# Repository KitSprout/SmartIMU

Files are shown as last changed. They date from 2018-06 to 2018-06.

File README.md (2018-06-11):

SmartIMU
========





SmartIMU 是一個集成微控制器（STM32F411）、3-Axis 加速度計、3-Axis 陀螺儀、3-Axis 電子羅盤與氣壓計（MPU9250、LPS22HB）以及無線傳輸（NRF52810）於一體的 10DOF 模組，控制器透過 UART 連接無線傳輸芯片，可以將感測器資料無線傳輸至其他裝置觀察。板上除了有 LED、按鍵、電源管理以及 RF 功率放大外，亦拉出至多 25pin 帶 ADC、UART、SPI、I2C 等功能的可用 I/O，1.27mm 間距的擴充腳位上下皆可連接，方便擴充不同應用，像是小型四軸飛行器。

Hardware
========
* 控制器 : [STM32F411CE](http://www.st.com/en/microcontrollers/stm32f411ce.html) 48Pin 100MHz DSP FPU / [nRF52810](https://www.nordicsemi.com/eng/Products/nRF52810) 32Pin 64MHz DSP
* 感測器 : [MPU9250](https://www.invensense.com/products/motion-tracking/9-axis/mpu-9250/) + [LPS22HB](http://www.st.com/content/st_com/en/products/mems-and-sensors/pressure-sensors/lps22hb.html)
* 設計軟體 [Altium Designer 17](http://www.altium.com/altium-designer/overview) ( PcbLib use AD [PcbLib v3.5](https://github.com/KitSprout/AltiumDesigner_PcbLibrary/releases/tag/v3.5) )

View
========

<br />

[more photo ...](https://goo.gl/photos/EfpjMtSc4LyJ7H2Q7)

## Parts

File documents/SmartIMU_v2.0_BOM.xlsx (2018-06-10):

Description | Type | Value | Quantity | Designator | Specification
Resistor | 0402 | 150R | 1 | R10 | -
 | 0402 | 680R | 1 | R7, R9 | -
 | 0402 | 1K | 4 | R1, R11, R12 | -
 | 0402 | 1.5K | 1 | R8 | -
 | 0402 | 10K | 5 | R2, R3, R4, R5, R6 | -
Capacitor | 0402 | 0.8pF | 1 | C26 | -
 | 0402 | 1.2pF | 1 | C27 | -
 | 0402 | 10pF | 4 | C12, C13, C21, C22 | -
 | 0402 | 100pF | 1 | C19 | -
 | 0402 | 220pF | 1 | C25 | -
 | 0402 | 10nF | 1 | C5 | -
 | 0402 | 0.1uF | 14 | C6, C7, C8, C9, C10, C14, C15, C16, C18, C24, C28, C29, C30, C31 | -
 | 0402 | 1uF | 1 | C20 | -
 | 0402 | 2.2uF | 3 | C3, C4, C11 | -
 | 0402 | 4.7uF | 2 | C17, C23 | -
 | 0805 | 4.7uF | 1 | C1 | -
 | 0805 | 22uF | 1 | C2 | -
Inductor | 0402 | 3.9nH | 1 | L4 | -
 | 0402 | 15nH | 1 | L2 | -
 | 0603 | 10uH | 1 | L3
 | 1008 | 4.7uH | 1 | L1 | -
Diode | SOD323 | ZLLS410TA | 1 | D1 | Schottky
LED | 0402 | BLUE | 1 | D4 | -
 | 0603 | WHITE | 1 | D2 | -
 | 1616 | RGB | 1 | D3 | -
IC | SOT23-5 | TPS613222A | 1 | U1 | Boost
 | SOT23-5 | XC6210-33 | 1 | U2 | 3V3
 | QFN48 P0.5 | STM32F411 | 1 | U3 | 100MHz
 | QFN32 P0.5 | nRF52810 | 1 | U4 | 64MHz
 | QFN16 P0.5 | RFX2401C | 1 | U5 | -
 | QFN24 P0.4 | MPU9250 | 1 | U6 | -
 | LGA10 P0.5 | LPS22HB | 1 | U7 | -
Crystal Oscillator | XTAL2016 | 16MHz | 1 | Y1 | -
 | XTAL2016 | 32MHz | 1 | Y2 | -
Connector | Micro USB | B-type | 1 | CON1 | -
 | MX | MX1.25_2P | 1 | CON2 | -
Button | 3.4x3.5 | TACT 4P | 1 | K1 | TACT 4P
Antenna | 3.2x1.6 | -0.5 dBi | 1 | A1 | 2.4GHz 50R

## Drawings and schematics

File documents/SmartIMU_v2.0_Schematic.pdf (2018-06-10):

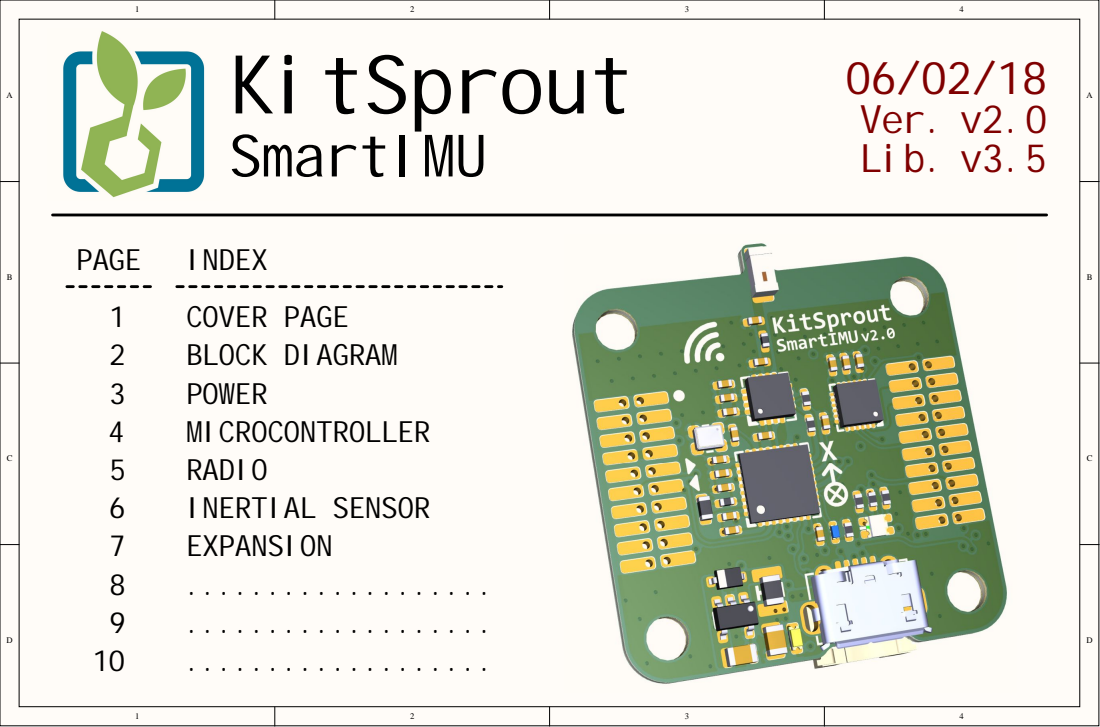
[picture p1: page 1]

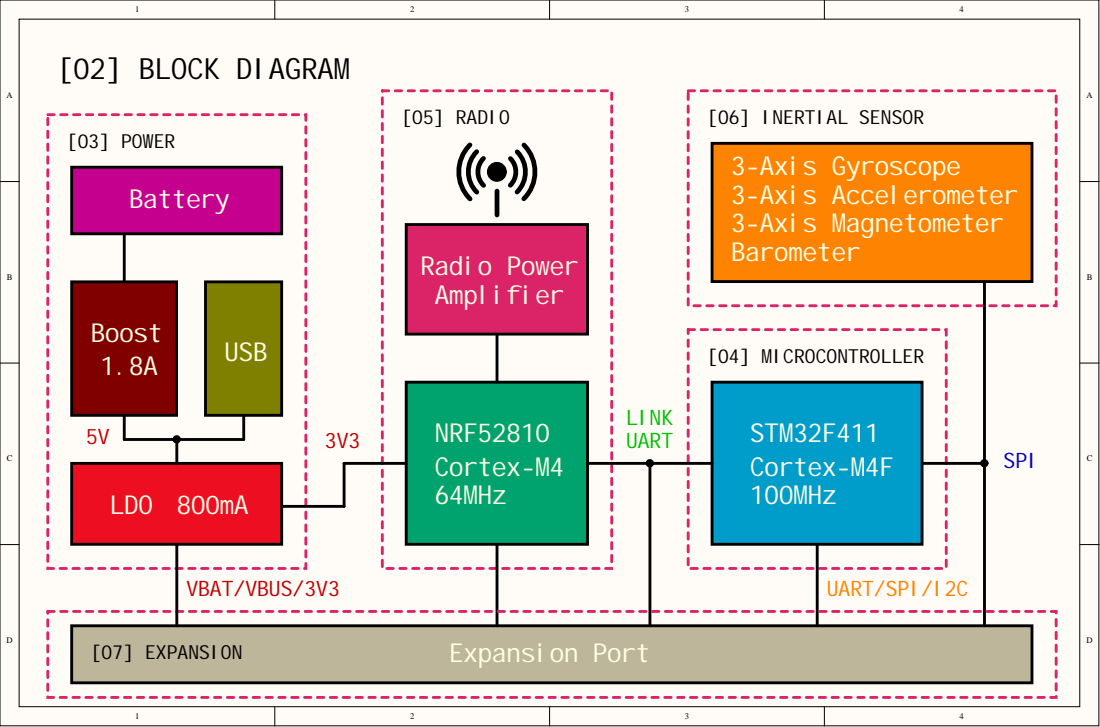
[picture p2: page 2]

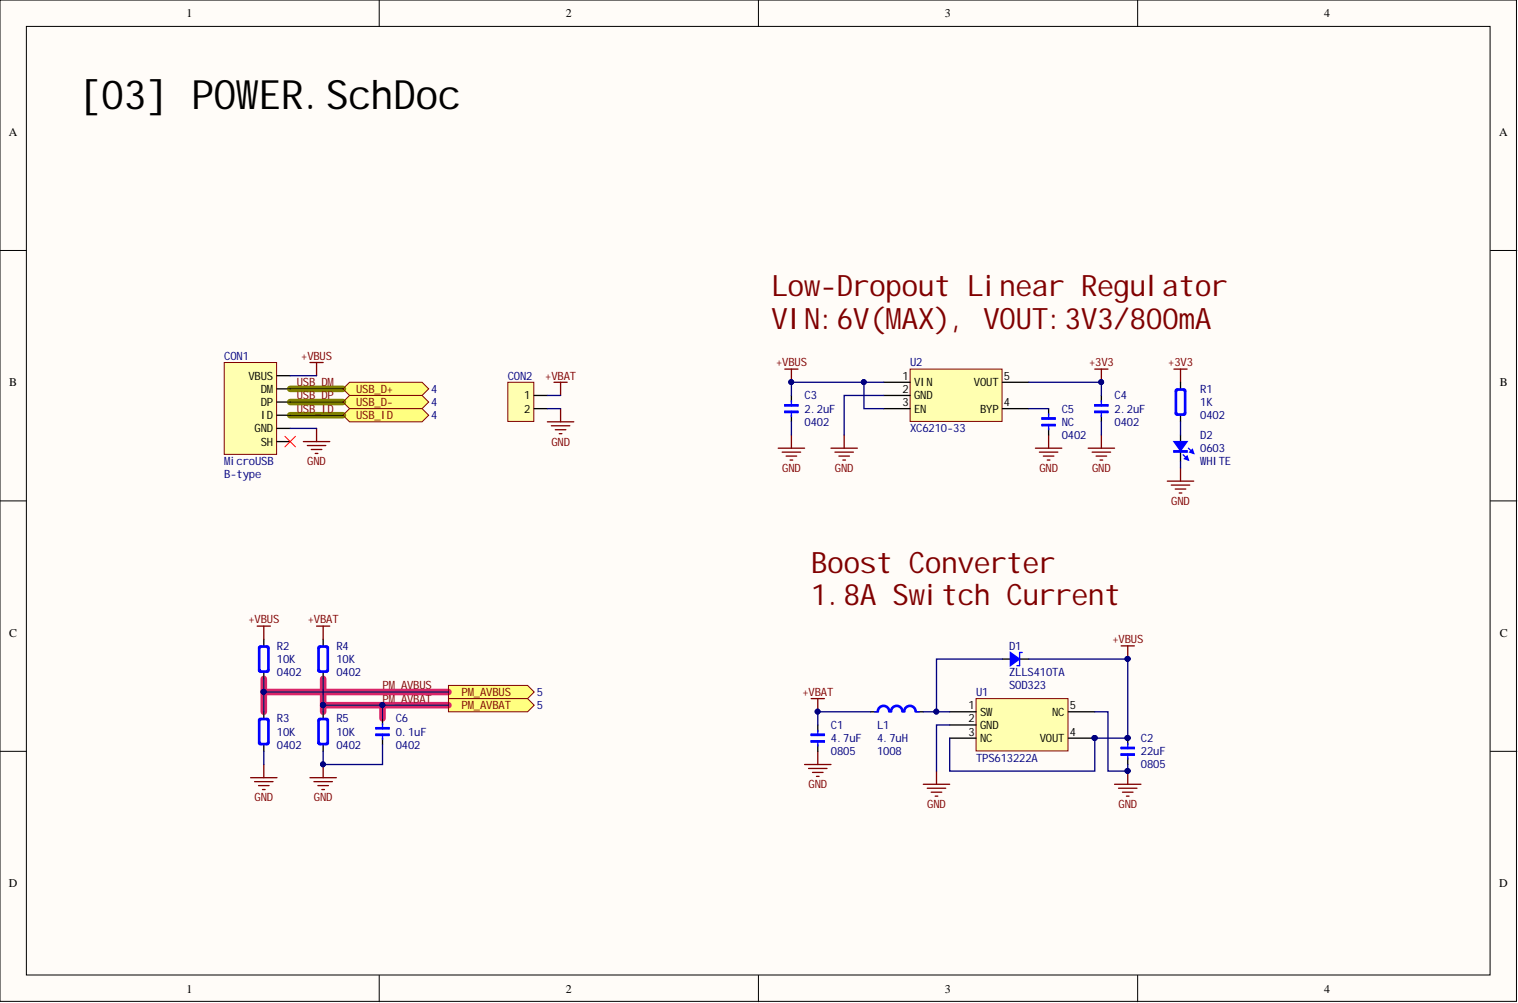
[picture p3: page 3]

Low-Dropout Linear Regulator
VIN:6V(MAX), VOUT:3V3/800mA

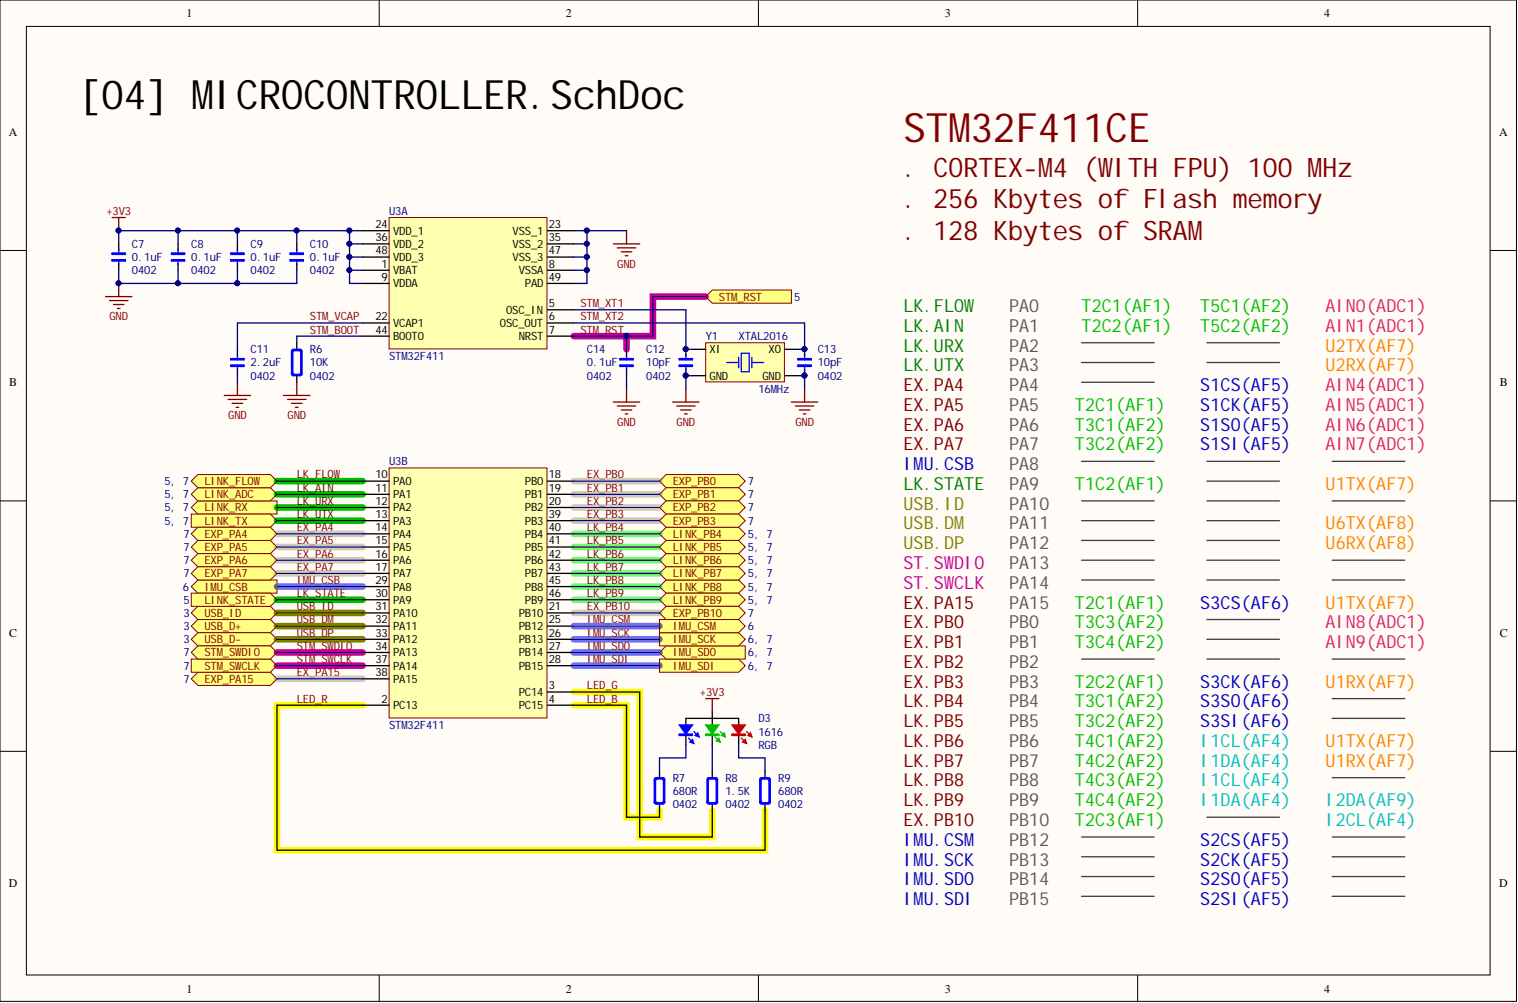
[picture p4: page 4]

STM32F411CE
. CORTEX-M4 (WITH FPU) 100 MHz
. 256 Kbytes of Flash memory
. 128 Kbytes of SRAM

GND | GND

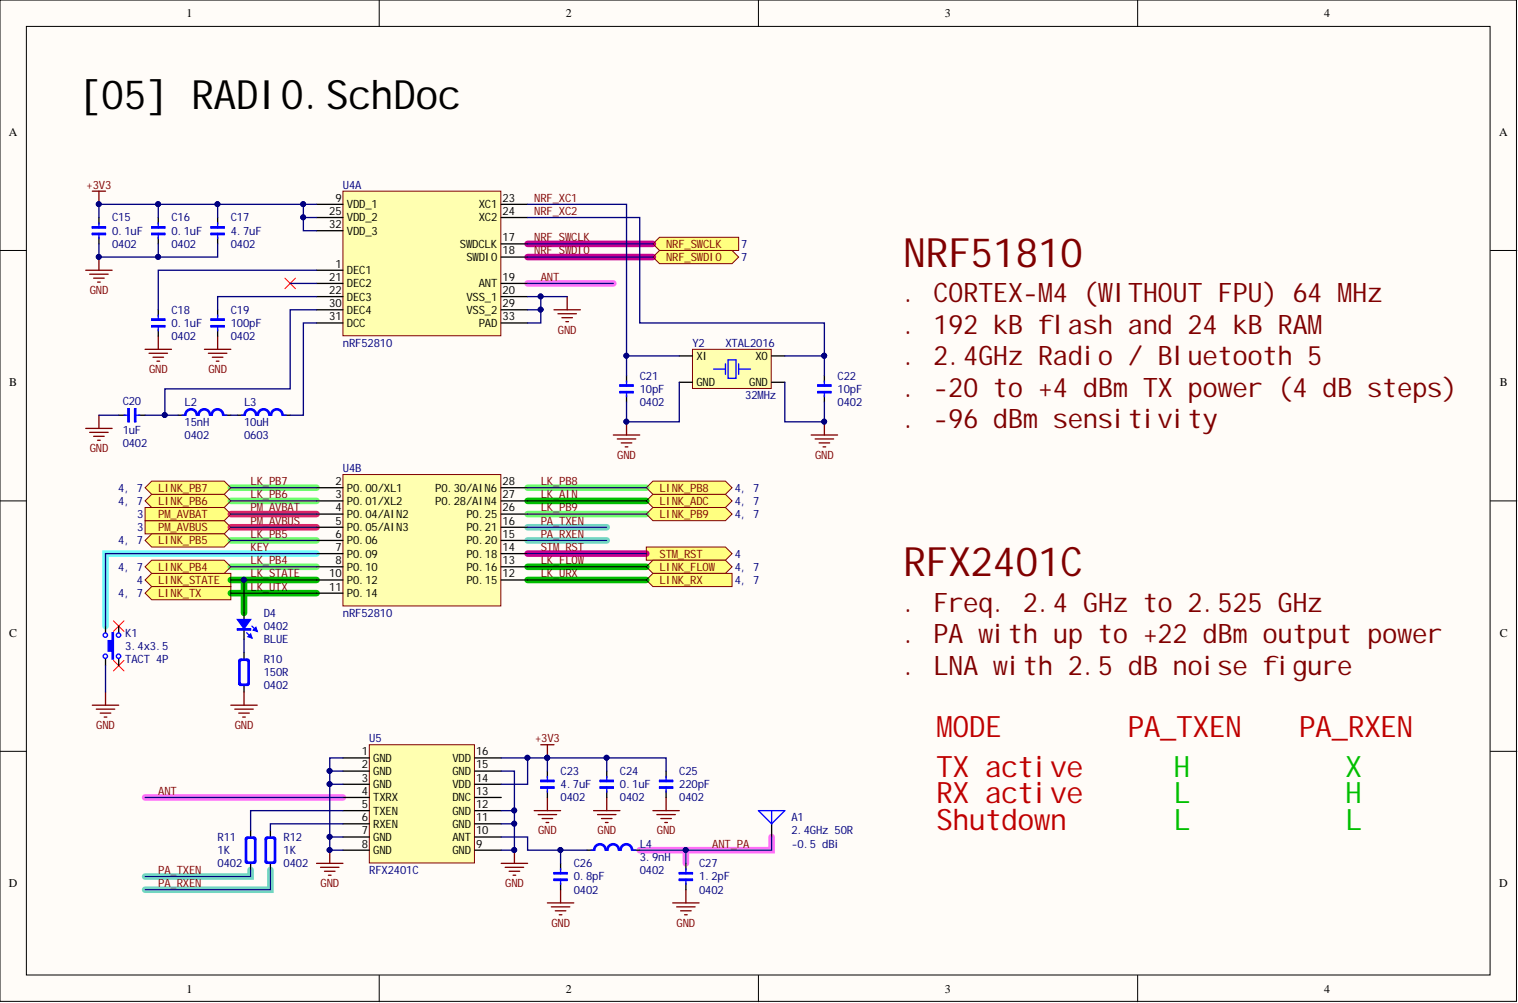
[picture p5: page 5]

NRF51810
. CORTEX-M4 (WITHOUT FPU) 64 MHz
. 192 kB flash and 24 kB RAM
. 2.4GHz Radio / Bluetooth 5
. -20 to +4 dBm TX power (4 dB steps)
. -96 dBm sensitivity

GND | GND

RFX2401C
. Freq. 2.4 GHz to 2.525 GHz
. PA with up to +22 dBm output power
. LNA with 2.5 dB noise figure

GND 2

TXRX 4
TXEN 5
RXEN 6
GND 7

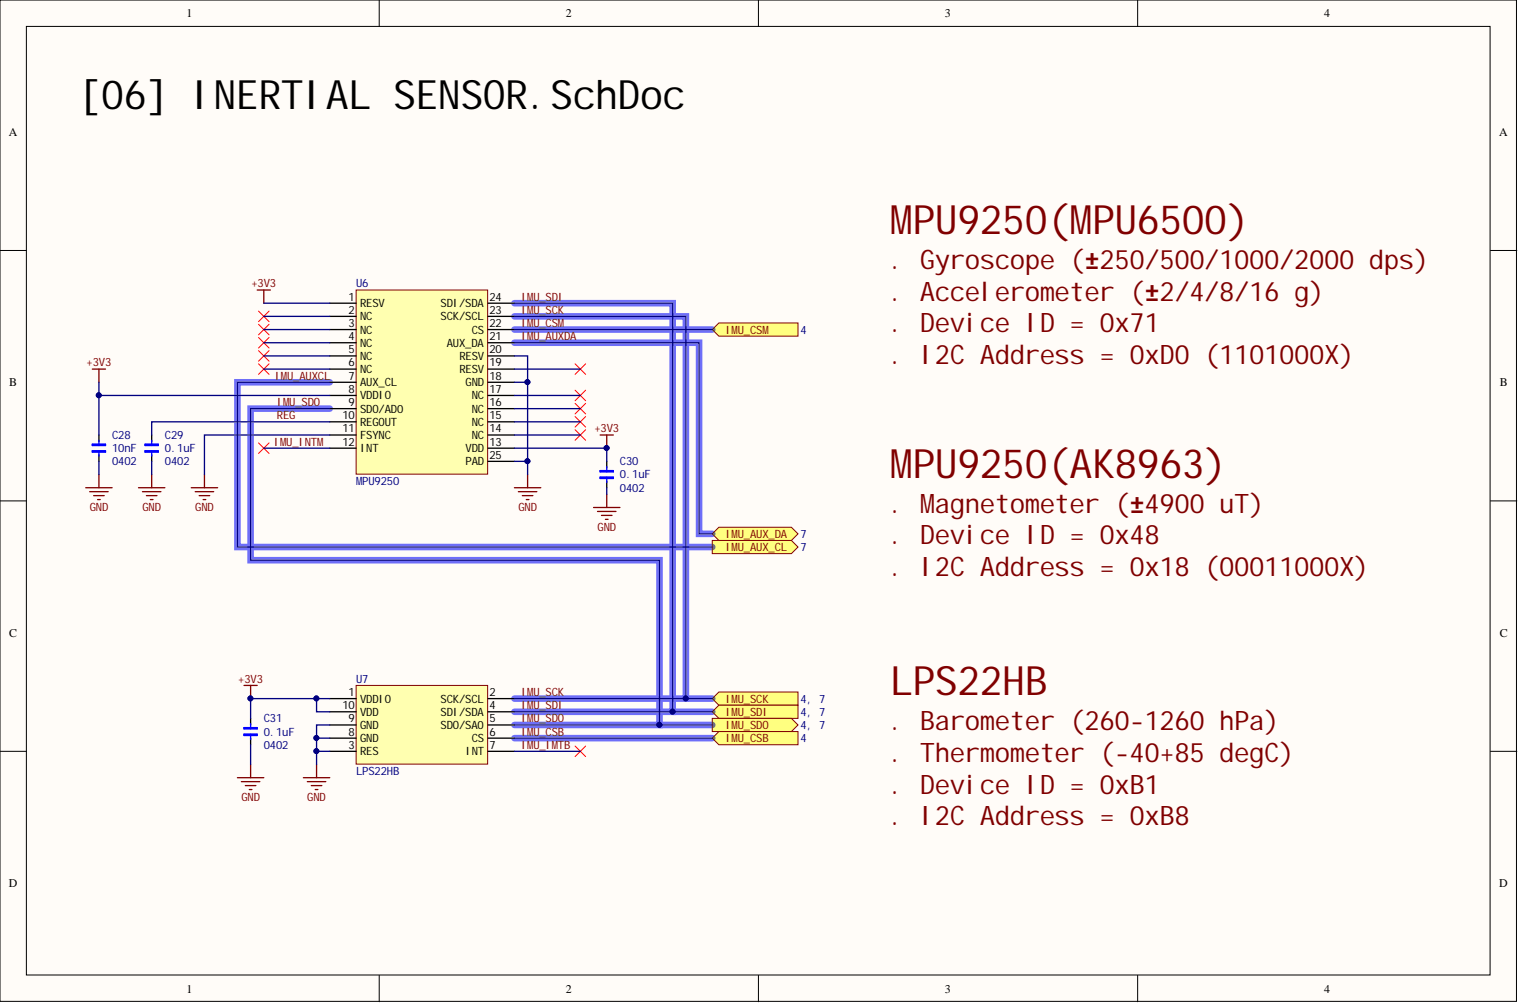
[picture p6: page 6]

NC 2 | IMU_SCK
NC 3 | IMU_CSM
NC 4 | IMU_AUXDA

VDDIO 8 REGOUT 10 | +3V3

IMU_SDO | SDO/AD0 9

FSYNC 11

IMU_INTM

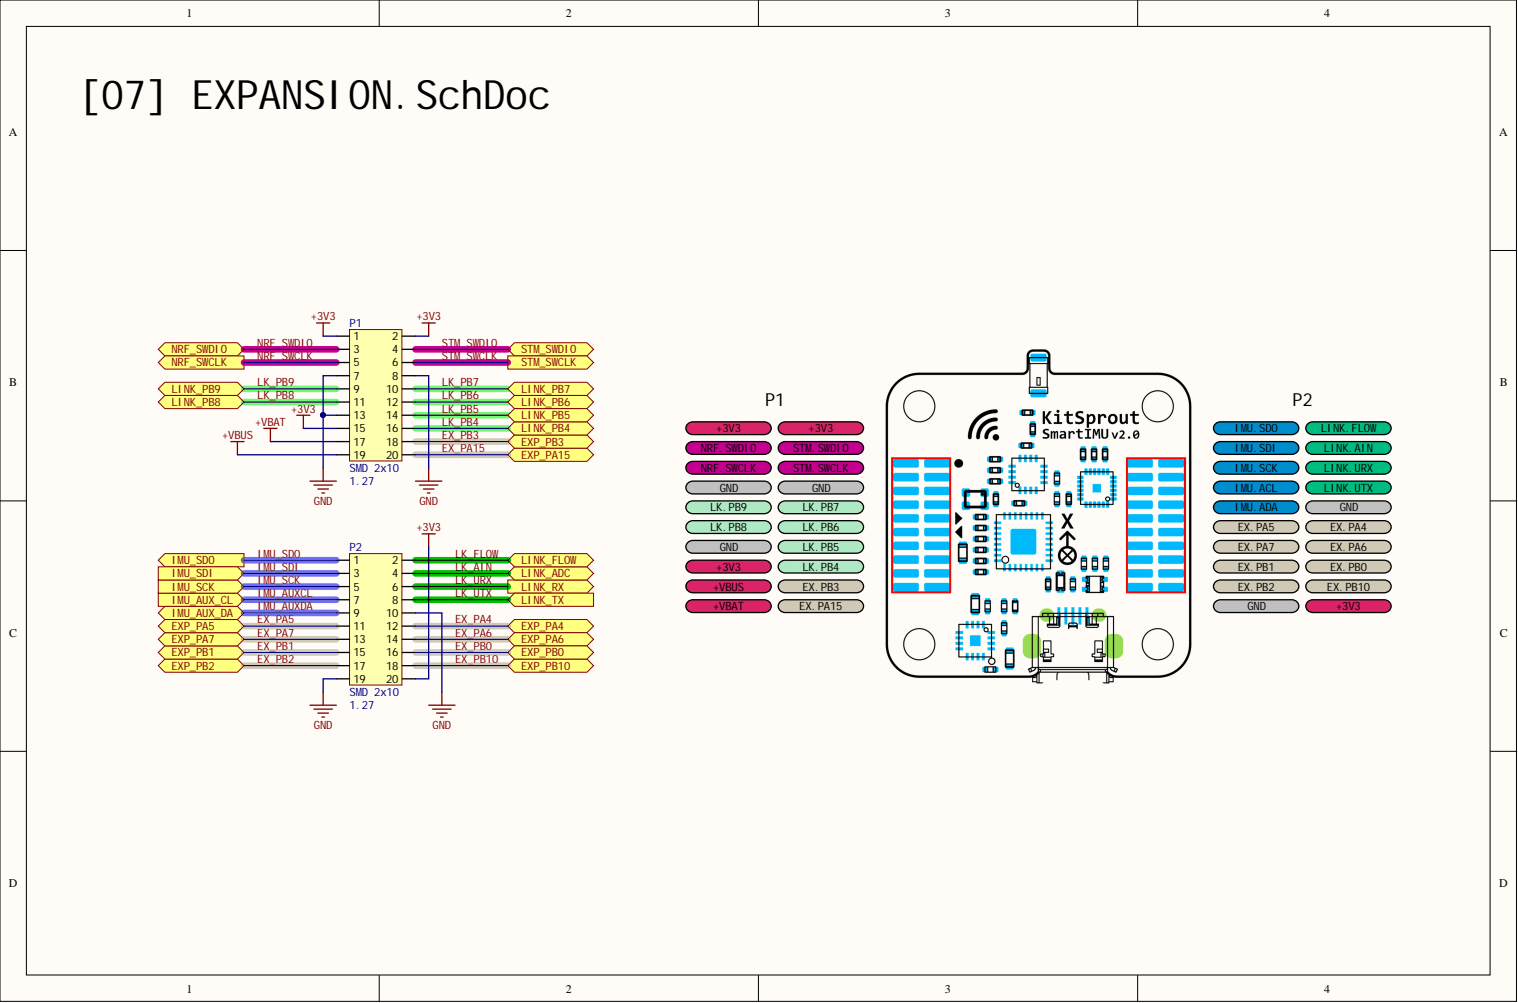
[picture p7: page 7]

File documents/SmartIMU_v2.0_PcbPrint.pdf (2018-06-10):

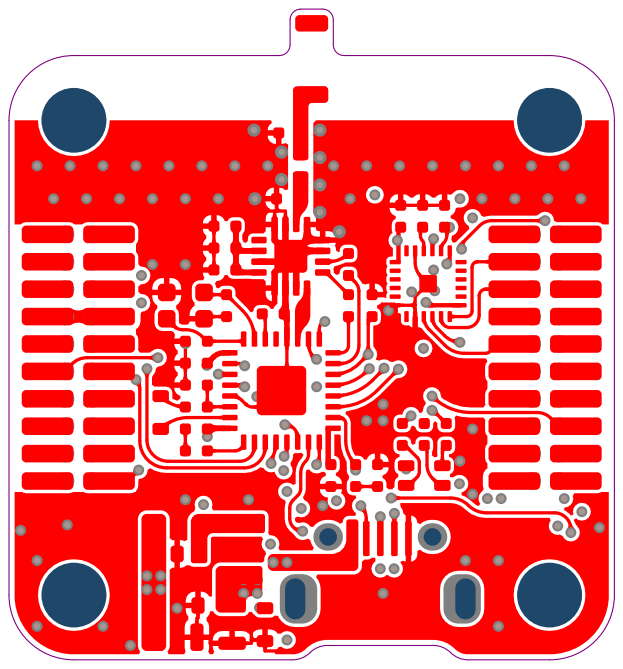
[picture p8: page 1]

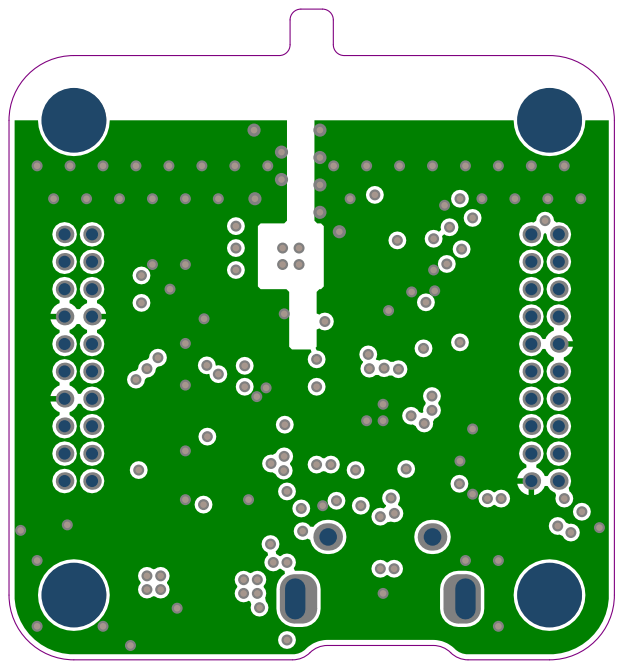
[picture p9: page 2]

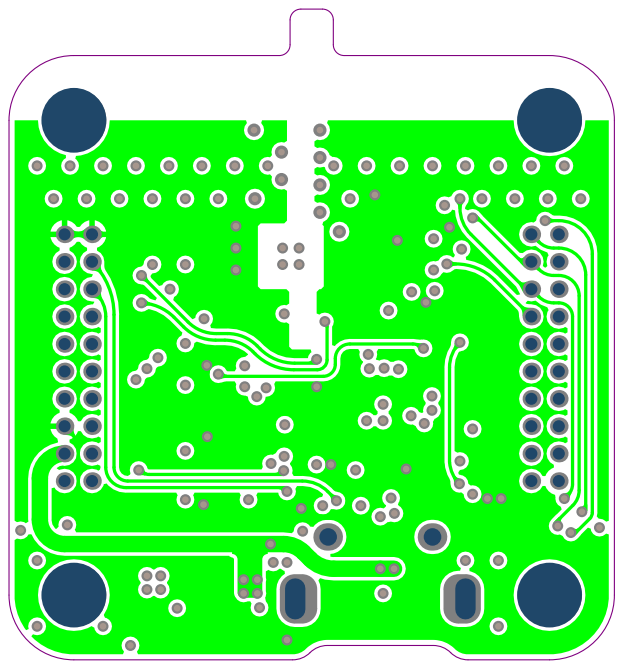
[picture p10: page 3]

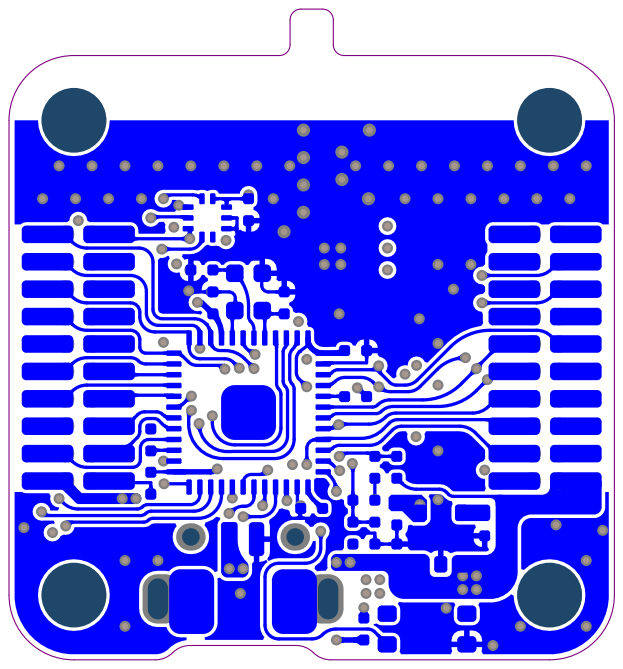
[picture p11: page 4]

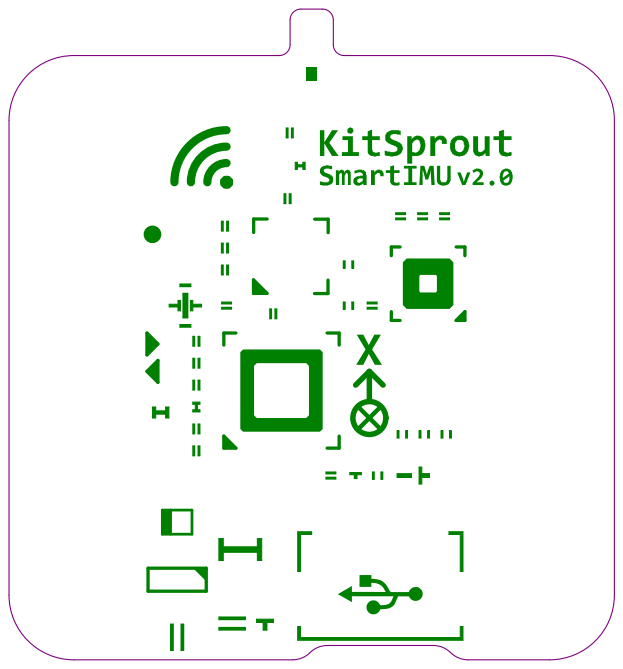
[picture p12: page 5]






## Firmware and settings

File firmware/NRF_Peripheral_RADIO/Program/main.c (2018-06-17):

/**
 *      __            ____
 *     / /__ _  __   / __/                      __  
 *    / //_/(_)/ /_ / /  ___   ____ ___  __ __ / /_ 
 *   / ,<  / // __/_\ \ / _ \ / __// _ \/ // // __/ 
 *  /_/|_|/_/ \__//___// .__//_/   \___/\_,_/ \__/  
 *                    /_/   github.com/KitSprout    
 * 
 *  @file    main.c
 *  @author  KitSprout
 *  @date    16-Jun-2018
 *  @brief   
 * 
 */

/* Includes --------------------------------------------------------------------------------*/
#include "drivers\nrf5x_system.h"
#include "drivers\nrf5x_radio.h"
#include "modules\serial.h"
#include "nrf5x_bsp.h"

/** @addtogroup NRF5x_Program
 *  @{
 */

/* Define ----------------------------------------------------------------------------------*/
#define MAX_LENS 128

/* Macro -----------------------------------------------------------------------------------*/
/* Typedef ---------------------------------------------------------------------------------*/
/* Variables -------------------------------------------------------------------------------*/
static int8_t rssi = 0;
static uint8_t packet[256];
static uint16_t lens = 0;
static uint16_t sequence = 0;

/* Prototypes ------------------------------------------------------------------------------*/
/* Functions -------------------------------------------------------------------------------*/

int main( void )
{
  bsp_gpio_init();
  bsp_serial_init(NULL);
  bsp_radio_init();

  if (KEY_Read()) {
    // RECV
    uint32_t status;
    printf(" >>> RECV MODE\r\n");
    while (1) {
      LED_Toggle();
      status = RADIO_RecvPacket(&sequence, packet, &lens, &rssi);
      if (status == KS_OK) {
        printf("[OK]");
      }
      else {
        printf("[ER]");
      }
      printf("[%06i][%03i][%04i dBm]", sequence, lens, rssi);
      printf("\r\n");
    }
  }
  else {
    // SEND
    printf(" >>> SEND MODE\r\n");
    while (1) {
      LED_Toggle();
      delay_ms(50);

      sequence++;
      for (uint32_t i = 0; i < MAX_LENS; i++) {
        packet[i] = i;
      }
      RADIO_SendPacket(sequence, packet, MAX_LENS);
    }
  }
}

/*************************************** END OF FILE ****************************************/

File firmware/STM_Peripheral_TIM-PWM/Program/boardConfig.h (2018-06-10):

/**
 *      __            ____
 *     / /__ _  __   / __/                      __  
 *    / //_/(_)/ /_ / /  ___   ____ ___  __ __ / /_ 
 *   / ,<  / // __/_\ \ / _ \ / __// _ \/ // // __/ 
 *  /_/|_|/_/ \__//___// .__//_/   \___/\_,_/ \__/  
 *                    /_/   github.com/KitSprout    
 * 
 *  @file    boardConfig.h
 *  @author  KitSprout
 *  @date    03-Jun-2018
 *  @brief   
 * 
 */

/* Define to prevent recursive inclusion ---------------------------------------------------*/
#ifndef __BOARDCONFIG_H
#define __BOARDCONFIG_H

#ifdef __cplusplus
  extern "C" {
#endif

/* Includes --------------------------------------------------------------------------------*/
/* Define ----------------------------------------------------------------------------------*/

#define KS_HW_BOARD_NAME                "SmartIMU"
#define KS_HW_MCU_NAME                  "STM32F411CE"

#define KS_HW_USE_CLOCK_SOUCE_INT       (0U)
#define KS_HW_USE_CLOCK_SOUCE_EXT       (1U)
#define KS_HW_HCLOCK_SOUCE              KS_HW_USE_CLOCK_SOUCE_EXT
#define KS_HW_LCLOCK_SOUCE              KS_HW_USE_CLOCK_SOUCE_INT

#define KS_FW_UART_HAL_LIBRARY          (0U)
#define KS_FW_SPI_HAL_LIBRARY           (0U)
#define KS_FW_I2C_HAL_LIBRARY           (0U)
#define KS_FW_USB_ENABLE                (1U)

#define KS_SYSCLK                       SystemCoreClock


/* -------- LED and KEY */

#define LED_R_PIN                       GPIO_PIN_13
#define LED_R_GPIO_PORT                 GPIOC
#define LED_R_Set()                     __GPIO_SET(LED_R_GPIO_PORT, LED_R_PIN)
#define LED_R_Reset()                   __GPIO_RST(LED_R_GPIO_PORT, LED_R_PIN)
#define LED_R_Toggle()                  __GPIO_TOG(LED_R_GPIO_PORT, LED_R_PIN)
#define LED_R_On()                      LED_R_Reset()
#define LED_R_Off()                     LED_R_Set()

#define LED_G_PIN                       GPIO_PIN_14
#define LED_G_GPIO_PORT                 GPIOC
#define LED_G_Set()                     __GPIO_SET(LED_G_GPIO_PORT, LED_G_PIN)
#define LED_G_Reset()                   __GPIO_RST(LED_G_GPIO_PORT, LED_G_PIN)
#define LED_G_Toggle()                  __GPIO_TOG(LED_G_GPIO_PORT, LED_G_PIN)
#define LED_G_On()                      LED_G_Reset()
#define LED_G_Off()                     LED_G_Set()

#define LED_B_PIN                       GPIO_PIN_15
#define LED_B_GPIO_PORT                 GPIOC
#define LED_B_Set()                     __GPIO_SET(LED_B_GPIO_PORT, LED_B_PIN)
#define LED_B_Reset()                   __GPIO_RST(LED_B_GPIO_PORT, LED_B_PIN)
#define LED_B_Toggle()                  __GPIO_TOG(LED_B_GPIO_PORT, LED_B_PIN)
#define LED_B_On()                      LED_B_Reset()
#define LED_B_Off()                     LED_B_Set()


/* -------- TIM Timer */

#define PWM_PRESCALER                   (uint32_t)(SystemCoreClock / 1000000)
#define PWM_PERIOD                      (uint32_t)(1000)
#define PWM_MAX                         PWM_PERIOD
#define PWM_MIN                         0

#define PWM_R                           TIM3
#define PWM_R_CLK_ENABLE()              __HAL_RCC_TIM3_CLK_ENABLE()
#define PWM_R_PERI                      PWM_R->PSC
#define PWM_R_PULSE                     PWM_R->ARR

#define PWM1_GPIO_PIN                   GPIO_PIN_1
#define PWM1_GPIO_PORT                  GPIOB
#define PWM1_GPIO_AF                    GPIO_AF2_TIM3
#define PWM1_CHANNEL                    TIM_CHANNEL_4
#define PWM1_DUTY                       PWM_R->CCR4

#define PWM4_GPIO_PIN                   GPIO_PIN_0
#define PWM4_GPIO_PORT                  GPIOB
#define PWM4_GPIO_AF                    GPIO_AF2_TIM3
#define PWM4_CHANNEL                    TIM_CHANNEL_3
#define PWM4_DUTY                       PWM_R->CCR3

#define PWM_L                           TIM4
#define PWM_L_CLK_ENABLE()              __HAL_RCC_TIM4_CLK_ENABLE()
#define PWM_L_PERI                      PWM_L->PSC
#define PWM_L_PULSE                     PWM_L->ARR

#define PWM2_GPIO_PIN                   GPIO_PIN_9
#define PWM2_GPIO_PORT                  GPIOB
#define PWM2_GPIO_AF                    GPIO_AF2_TIM3
#define PWM2_CHANNEL                    TIM_CHANNEL_4
#define PWM2_DUTY                       PWM_L->CCR4

#define PWM3_GPIO_PIN                   GPIO_PIN_8
#define PWM3_GPIO_PORT                  GPIOB
#define PWM3_GPIO_AF                    GPIO_AF2_TIM3
#define PWM3_CHANNEL                    TIM_CHANNEL_3
#define PWM3_DUTY                       PWM_L->CCR3


/* Macro -----------------------------------------------------------------------------------*/
/* Typedef ---------------------------------------------------------------------------------*/
/* Extern ----------------------------------------------------------------------------------*/
/* Functions -------------------------------------------------------------------------------*/


#ifdef __cplusplus
}
#endif

#endif

/*************************************** END OF FILE ****************************************/

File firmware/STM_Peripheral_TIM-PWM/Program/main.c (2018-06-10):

/**
 *      __            ____
 *     / /__ _  __   / __/                      __  
 *    / //_/(_)/ /_ / /  ___   ____ ___  __ __ / /_ 
 *   / ,<  / // __/_\ \ / _ \ / __// _ \/ // // __/ 
 *  /_/|_|/_/ \__//___// .__//_/   \___/\_,_/ \__/  
 *                    /_/   github.com/KitSprout    
 * 
 *  @file    main.c
 *  @author  KitSprout
 *  @date    03-Jun-2018
 *  @brief   
 * 
 */

/* Includes --------------------------------------------------------------------------------*/
#include "drivers\stm32f4_system.h"
#include "drivers\stm32f4_tim_pwm.h"
#include "stm32f4xx_bsp.h"

/** @addtogroup STM32_Program
 *  @{
 */

/* Define ----------------------------------------------------------------------------------*/
/* Macro -----------------------------------------------------------------------------------*/
/* Typedef ---------------------------------------------------------------------------------*/
/* Variables -------------------------------------------------------------------------------*/
/* Prototypes ------------------------------------------------------------------------------*/
/* Functions -------------------------------------------------------------------------------*/

int main( void )
{
  uint8_t state = 0;
  uint32_t i = PWM_MIN;

  bsp_gpio_init();
  bsp_tim_pwm_init();

  while(1) {
    i = (state) ? (i - 1) : (i + 1);
    if (i == PWM_MAX){ state = 1; }
    if (i == PWM_MIN){ state = 0; }

    TIM_PWM_SetDuty(1, i);
    TIM_PWM_SetDuty(2, i);
    TIM_PWM_SetDuty(3, i);
    TIM_PWM_SetDuty(4, i);

    LED_G_Toggle();
    delay_ms(5);
  }
}

/*************************************** END OF FILE ****************************************/

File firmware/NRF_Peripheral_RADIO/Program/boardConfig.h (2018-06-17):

/**
 *      __            ____
 *     / /__ _  __   / __/                      __  
 *    / //_/(_)/ /_ / /  ___   ____ ___  __ __ / /_ 
 *   / ,<  / // __/_\ \ / _ \ / __// _ \/ // // __/ 
 *  /_/|_|/_/ \__//___// .__//_/   \___/\_,_/ \__/  
 *                    /_/   github.com/KitSprout    
 * 
 *  @file    boardConfig.h
 *  @author  KitSprout
 *  @date    16-Jun-2018
 *  @brief   
 * 
 */

/* Define to prevent recursive inclusion ---------------------------------------------------*/
#ifndef __BOARDCONFIG_H
#define __BOARDCONFIG_H

#ifdef __cplusplus
  extern "C" {
#endif

/* Includes --------------------------------------------------------------------------------*/
/* Define ----------------------------------------------------------------------------------*/

#define KS_HW_BOARD_NAME                "SmartIMU"
#define KS_HW_MCU_NAME                  "NRF52810"

#define KS_HW_USE_CLOCK_SOUCE_INT       (0U)
#define KS_HW_USE_CLOCK_SOUCE_EXT       (1U)
#define KS_HW_HCLOCK_SOUCE              KS_HW_USE_CLOCK_SOUCE_EXT
#define KS_HW_LCLOCK_SOUCE              KS_HW_USE_CLOCK_SOUCE_INT

#define KS_SYSCLK                       SystemCoreClock


/* -------- LED and KEY */

#define LED_PIN                         12
#define LED_PORT                        NRF_P0
#define LED_Set()                       __GPIO_SET(LED_PORT, LED_PIN)
#define LED_Reset()                     __GPIO_RST(LED_PORT, LED_PIN)
#define LED_Toggle()                    __GPIO_TOG(LED_PORT, LED_PIN)
#define LED_On()                        LED_Set()
#define LED_Off()                       LED_Reset()

#define KEY_PIN                         9
#define KEY_PORT                        NRF_P0
#define KEY_Read()                      (__GPIO_READ(KEY_PORT, KEY_PIN) == RESET)


/* -------- Timer */

#define TIMERx                          NRF_TIMER0
#define TIMERx_IRQn                     TIMER0_IRQn
#define TIMERx_IRQn_PRIORITY            1
#define TIMERx_MODE                     NRF_TIMER_MODE_TIMER
#define TIMERx_PRESCALER                NRF_TIMER_FREQ_1MHz
#define TIMERx_BIT_MODE                 NRF_TIMER_BIT_WIDTH_32

#define TIMERx_CHANNEL                  NRF_TIMER_CC_CHANNEL0
#define TIMERx_CHANNEL_PERIOD           1000


/* -------- Serial */

#define SERIAL_MAX_TXBUF                32
#define SERIAL_MAX_RXBUF                32

#define SERIAL_UARTEx                   NRF_UARTE0
#define SERIAL_UARTEx_IRQn              UARTE0_IRQn
#define SERIAL_UARTEx_IRQn_PRIORITY     1

#define SERIAL_TXD_PIN                  30
#define SERIAL_RXD_PIN                  25
#define SERIAL_RTS_PIN                  2
#define SERIAL_CTS_PIN                  2
#define SERIAL_BAUDRATE                 NRF_UARTE_BAUDRATE_115200
#define SERIAL_PARITY                   NRF_UARTE_PARITY_EXCLUDED
#define SERIAL_HARDWARECTRL             NRF_UARTE_HWFC_DISABLED
#define SERIAL_INTERRUPT_MODE           NRF_UARTE_INT_RXDRDY_MASK


/* -------- 2.45GHz Radio */

//#define RADIOx                          NRF_RADIO
#define RADIO_RF_FREQ                   22UL   // 2422 MHz
#define RADIO_TX_POWER                  RADIO_TXPOWER_TXPOWER_Pos4dBm
#define RADIO_SPEED                     RADIO_MODE_MODE_Nrf_1Mbit
#define RADIO_CRC                       RADIO_CRCCNF_LEN_Two

#define RADIO_RXEN_PIN                  20
#define RADIO_RXEN_PORT                 NRF_P0
#define RADIO_RXEN_On()                 __GPIO_SET(RADIO_RXEN_PORT, RADIO_RXEN_PIN)
#define RADIO_RXEN_Off()                __GPIO_RST(RADIO_RXEN_PORT, RADIO_RXEN_PIN)

#define RADIO_TXEN_PIN                  21
#define RADIO_TXEN_PORT                 NRF_P0
#define RADIO_TXEN_On()                 __GPIO_SET(RADIO_TXEN_PORT, RADIO_TXEN_PIN)
#define RADIO_TXEN_Off()                __GPIO_RST(RADIO_TXEN_PORT, RADIO_TXEN_PIN)


/* Macro -----------------------------------------------------------------------------------*/
/* Typedef ---------------------------------------------------------------------------------*/
/* Extern ----------------------------------------------------------------------------------*/
/* Functions -------------------------------------------------------------------------------*/


#ifdef __cplusplus
}
#endif

#endif

/*************************************** END OF FILE ****************************************/

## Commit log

2014-01-07 Add SmartIMU 01/07
    新建 Readme.md 檔案
2014-01-09 Update Readme.md 01/09
    更新 PCB LIB 連結
2014-01-23 Update Readme.md 01/23
    修改 HARDWARE 規格錯誤＆詳細授權相關
2014-01-24 Add Per Hardware v1.0
    [SmartIMU.PrjPCB, SmartIMU_Sch.SchDoc, SmartIMU__Pcb.PcbDoc]
2014-01-26 Update SmartIMU 01/27
    加入預計功能及想法
2014-01-27 Update README 01/27
    加入更新紀錄連結
2014-01-27 Update README 01/27
    微調排版
2014-01-27 Update README 01/28
    加入 SmartIMU 架構圖
2014-02-01 Update README 02/01
    加入 SmartIMU 電路圖
2014-02-04 Update README 02/04
    調整 SmartIMU 的電路圖
2014-02-04 Update Hardware 02/04
    更新目前 PCB LAYOUT
    [SmartIMU_Sch.SchDoc, SmartIMU__Pcb.PcbDoc]
2014-02-15 Update README 02/15
    更換 MCU ( STM32F103T → STM32F401C )，對浮點數運算有更高的能力。
2014-02-15 Update README 02/15
    更新電路圖 STM32F401C 版本
2014-02-18 Update README 02/19
    更新架構圖及簡介
2014-02-19 Update Hardware v1.0 02/20
    更新 v1.0 版本電路
    [SmartIMU.PrjPCB, SmartIMU_Sch.SchDoc, SmartIMU__Pcb.PcbDoc]
2014-03-02 Update Hardware v1.0 03/03
    調整 Top Overlay
    [SmartIMU_Sch.SchDoc, SmartIMU__Pcb.PcbDoc]
2014-03-02 Update README 03/03
    加入 IC 腳位配置圖
2014-03-10 Update README & LICENSE 03/11
    更新進度，將 LICENSE 創用 CC 部分內容改成中文
2014-03-18 Update README 03/19
    更新進度及簡介
2014-04-11 Update Hardware TestBoard 4/12
    [SmartIMU_TestBoard.PrjPCB, SmartIMU_TestBoard_Pcb.PcbDoc, SmartIMU_TestBoard_Sch.SchDoc]
2014-04-11 Update Schematic PDF 04/12
    [SmartIMU_TestBoard.PrjPCB, SmartIMU_TestBoard_Sch.SchDoc]
2014-04-13 Update README 04/13
    為修正 MS5611 轉換時，MPU9250 必須等待問題，
    將獨立出一個 SPI 來讀取 MS5611，重新規劃了配置。
2014-04-18 Update Test_SmartIMU_LED 04/19
    LED 測試程式
2014-04-19 Update TEST_SmartIMU_Systick 04/19
    Systick 測試程式
2014-04-19 Update TEST_SmartIMU_PWM 04/19
    PWM 測試程式
2014-04-20 Update TEST_SmartIMU_UART 04/20
    UART 測試程式
2014-04-20 Update TEST_SmartIMU_ADC 04/20
    ADC 測試程式
2014-04-20 Update TEST_SmartIMU_MPU9250 04/20
    MPU9250 測試程式，僅讀出 Device ID 做確認
2014-04-20 Update README 04/20
    更新電路圖和 IO 配置
2014-04-21 Update Hardware Pre-v1.2 04/21
    [SmartIMU.PrjPCB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]
2014-04-21 Update License 04/22
    完善 SmartIMU v1.2 授權訊息
2014-04-23 Update README 04/23
    更新圖片
2014-04-24 Update README 04/24
    硬體尺寸示意圖加入 IC 方向
2014-05-05 Update Hardware v1.2 05/05
    v1.2 版本
    [SmartIMU_Pcb.PcbDoc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]
2014-05-05 Update TEST_SmartIMU_LED 05/05
    調整腳位以符合 v1.2 版本
2014-05-05 Update TEST_SmartIMU_UART 05/05
    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
2014-05-05 Update README 05/05
    修正 PCB 尺寸大小
2014-05-05 Update TEST_SmartIMU_MPU9250 05/05
    調整腳位以符合 v1.2 版本，另外加入 AK8963 ID 讀取
2014-05-11 Update TEST_SmartIMU_IMU 05/11
    將 MPU9250 測試改成 IMU 測試，並加入角度計算
2014-05-11 Update README 05/12
    更新電路圖 & v1.4 版本預計改版內容
2014-06-09 Update README 06/10
    更新進度 - 完成外部讀取 MPU9250 測試
2014-08-13 Update README 08/13
    電路圖上的 VCAP ( C1 ) 應接至 GND，但接至 3V3 版本目前使用尚未出現問題。
2014-11-16 Update README 11/17
    新增預計更新內容
2015-03-11 Update README 03/11
    更新 SmartIMU 下次預計更新內容
2016-04-05 Update Hardware v2.0 04/05
    [SmartIMU-BAT.PrjPCB, SmartIMU-BAT_Pcb.PcbDoc, SmartIMU-BAT_Sch.SchDoc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]
2016-04-06 Update Hardware v2.0 04/06
    [SmartIMU-BAT.PrjPCB, SmartIMU-BAT_Pcb.PcbDoc, SmartIMU-BAT_Sch.SchDoc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]
2016-10-14 Creat document 10/14
    [SmartIMU v2.0_Config.xlsx, SmartIMU-Dev_v1.0_Config.xlsx]
2016-10-14 Update hardware SmartIMU_Devv1.0 10/14
    [SmartIMU_Dev.PrjPCB, SmartIMU_Dev_Sch.SchDoc, SmartIMU_v2.0_Config.xlsx]
2016-11-05 Change name SmartIMU dev to SmartIMU 11/05
    [SmartIMU-BAT.PrjPCB, SmartIMU-BAT_Pcb.PcbDoc, SmartIMU-BAT_Sch.SchDoc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]
2016-11-05 Add Hardware v1.2 11/05
    [SmartIMU.PrjPCB, SmartIMU_Dev.PrjPCB, SmartIMU_Dev_Sch.SchDoc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]
2016-11-05 Add Documents 11/05
    [SmartIMU-Dev_v1.0_Config.xlsx]
2016-11-12 Add Hardware v1.4 11/12
    [SmartIMU.PrjPCB, SmartIMU_I2C.PrjPCB, SmartIMU_I2C_Sch.SchDoc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]
2018-04-22 Add Hardware v2.0 04/22
    [SmartIMU.PcbDoc, SmartIMU.PrjPCB, SmartIMU_Sch.SchDoc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]
2018-04-22 Add Documents 04/22
    [SmartIMU_v2.0_BOM.xlsx]
2018-06-10 Update Hardware v2.0 06/10
    [SmartIMU.PrjPCB, [01] COVER PAGE.SchDoc, [02] BLOCK DIAGRAM.SchDoc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]
2018-06-10 Update Documents 06/10
    [SmartIMU_v2.0_BOM.xlsx]
2018-06-10 Add STM_Peripheral_TIM-PWM 06/10

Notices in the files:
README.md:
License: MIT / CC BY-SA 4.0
